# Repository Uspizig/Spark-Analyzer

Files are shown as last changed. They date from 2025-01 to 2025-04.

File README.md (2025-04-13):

# Spark Analyzer: The Programmable USB-C Power Delivery Analyzer & Power Supply

<p align="center">
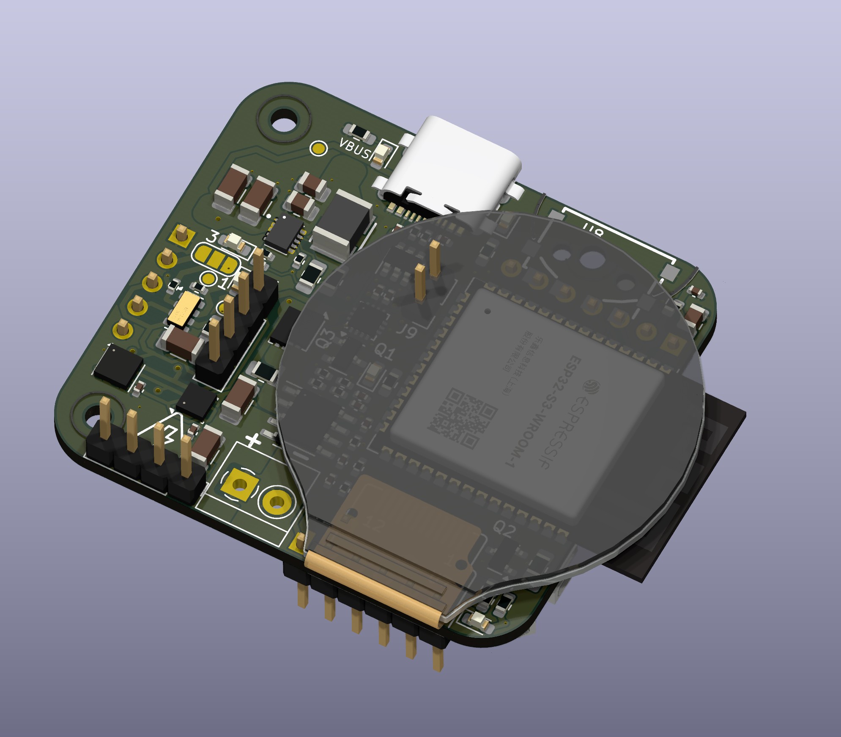
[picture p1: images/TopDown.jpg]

</p>

This is a modification of Spark Analyser to my personal needs. Please check the original Product here [now](https://www.crowdsupply.com/elektrothing/spark-analyzer).

The **Spark Analyzer** excels in power management. It is a versatile ESP32-powered device tailored for enhancing project development and debugging processes. It is fully compatible with USB-C Power Delivery (PD) and also supports the Programmable Power Supply (PPS) feature, allowing for precise control and management of power. Its compact design facilitates easy inline integration with existing setups, providing essential insights and control over power delivery.

Equipped with WiFi and BLE, the Spark Analyzer offers wireless connectivity, enabling developers to remotely monitor and adjust voltage levels, log data, and analyze power consumption through a user-friendly interface. This design prioritizes convenience and efficiency, removing the need for physical buttons and supporting distance operation.

## Features:

1. **Configure USB Power Delivery PD**: When the Spark Analyzer is connected to a USB port that supports Power Delivery (PD), you can configure the output voltage as 5V, 9V, 15V or 20V.

2. **Configure USB Programmable Power Supply PPS**: When the Spark Analyzer is connected to a USB port that supports Programmable Power Supply (PPS), then you can configure the output voltage between 3.3V and 21V in steps of 20 mV. You can also limit the current up to 3A in steps of 50mA.

3. **Power Analysis**: The Spark Analyzer comes with a current sensor. This allows for accurate current draw measurements, essential for understanding power usage in your projects.

4. **Wireless Control**: Untehther your development process with the Spark Analyzer’s wireless capabilities. With both WiFi and BLE, this tool allows remote control and data logging. Users can adjust settings and monitor data from a distance, offering a more flexible development experience.

5. **Open Source & Programmable**: As an open-source device, the Spark Analyzer offers unmatched versatility. It is fully programmable, allowing you to tailor its functionality to your specific applications. This customization extends to software and hardware, opening up endless possibilities for creative and efficient project development.

6. **Compact Design**: Designed for convenience, the Spark Analyzer's compact and sleek form factor allows for seamless integration into existing setups. Its compatibility with USB PD power sources and inline integration capability minimizes the need for additional equipment or extensive redesign, making it a versatile and user-friendly addition to any development environment.

5. **Safety**: Safety is crucial when working with electricity and is at the heart of Spark Analyzer. An integrated output FET allows for software programmable current limit that switches off the power in high-current scenarios.

6. **Data Storage**: Store your Voltage Curves on SD Card and play back voltage ramps

7. **Display**: Monitor live the current status of the Voltage Source

8. **RTC**: Operate the Device in remote areas without Wifi in Standalone mode and still have a proper Time Monitoring

9. **Air Quality**: Measure the Air Qulity with the BME680, BME688 or BME690: Temperature, Humidity, Pressure and eCO² to take actions based on Enviromental Data

10. **Gyro, ACC**: Identify Movement of the Device and take actions.

## Specifications

#### Power
- **Negotiable Power Delivery**: Options of 5 VDC, 9 VDC, 12 VDC, 15 VDC, 20 VDC; max 5 A (100 W at 20 VDC). It is also PPS compatible up to 21 VDC. Note: the Spark Analyzer comes preinstalled with firmware that supports PD. If you want to use PPS you can load this version instead: [WebApp_PPS](https://github.com/tooyipjee/Spark-Analyzer/tree/master/PlatformIO/WebApp_PPS).
- **USB Type-C Port**: For power delivery and integrated JTAG programming.
- **ON Semiconductor [FUSB302MPX](https://www.onsemi.com/pdf/datasheet/fusb302b-d.pdf)**: Programmable USB Type-C control and USB PD communication.
- **ESD Protection**: On D+/D-/CC1/CC2 pins.
- **Texas Instruments [TPS62175DQCT](https://www.ti.com/product/TPS62175/part-details/TPS62175DQCT)**: 3.3 VDC 0.5 A max output DC-DC Step-Down Converter.
- **Power Output**: 3.5 mm, 2-position terminal block.

#### I/O Configuration
- **GPIOs**: 4 GPIOs (I2C, UART, SPI compatible).
- **Power Pins**: 1x 5 VDC and 1x GND.

#### Microcontroller
- **Model**: [ESP32-S3 Wroom](https://www.espressif.com/sites/default/files/documentation/esp32-s3-wroom-1_wroom-1u_datasheet_en.pdf) 
- **Wi-Fi**: 802.11b/g/n.
- **Bluetooth**: BLE 4.2.
- **Flash Memory**: 4 MB.

#### Interface
- **3x LED Indicators**
  - Power On
  - Output Enable
  - Programmable LED/Debug
  - 2 x WS2812-4020 RGB Edge LED
- **Display**
  - GCA9a01 240x240 round Display
  - Backlight can be operated seperatly
- **Buttons**
  - Reset
  - Programmable 2Buttons/Debug
  - Jog Dial
- **Sensors**
  - LSM6 Gyro
  - RV3028 RTC Ultra Low Power
  - 4 GPIOs(3V3 logic) for operating outputs or read out Tacho Signals of FANs
  - BME280 (optional)
  - BME680 (optional) or - BME688 (optional) or - BME690 (optional)
- **Audio Amplifier**
  - MAX983657 AMP for Loudspeaker

#### Programming
- **RX/TX Pins**: For programming.
- **Micro SD Card**: For recall configuration files.
- **USB-C**: Built-in USB JTAG programmer (ESP32-S3), compatible with Arduino. Select ESP32-S3 Dev Board.

#### Output
- **Current Output**: [CC6904SO-10A](https://datasheet.lcsc.com/lcsc/2304140030_Cross-chip-CC6904SO-10A_C469389.pdf).
- **Current Sensor**: Hall Effect Current Sensor.
- **Output Enable**: [DMP3017SFG-7 FET](https://www.diodes.com/assets/Datasheets/products_inactive_data/DMP3017SFG.pdf).

<p align="center">
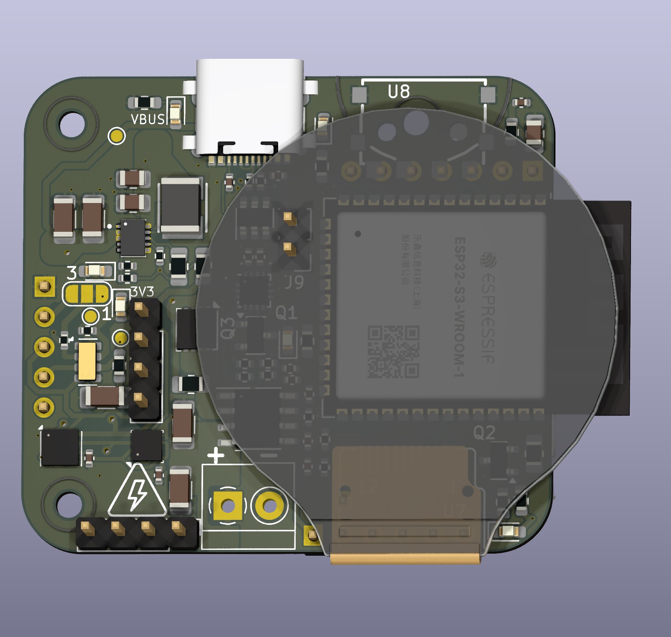
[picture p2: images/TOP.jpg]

</p>

<p align="center">
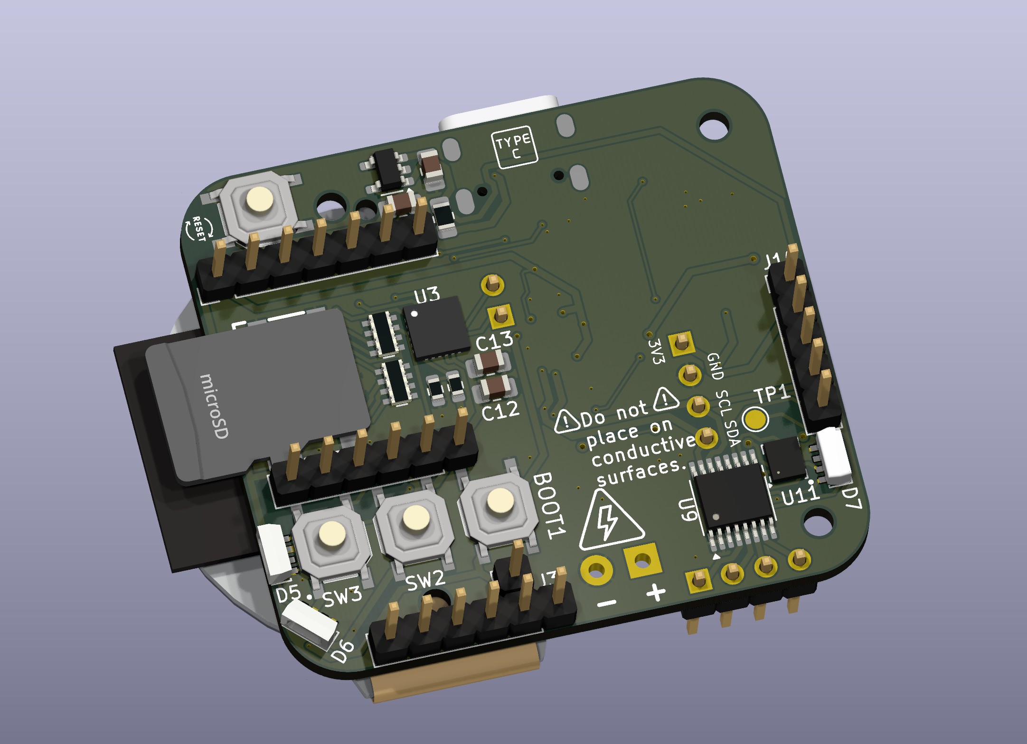
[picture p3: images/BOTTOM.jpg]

</p>

## Spark Analyzer Mobile App

<p align="center">

</p>

> **Note**: The Spark Analyzer Mobile App is currently in active development. The features described below are subject to change as we continue to improve the app.

The Spark Analyzer Mobile App, currently done for [Android](https://play.google.com/store/apps/details?id=com.elektrothing.SparkAnalyzer&hl=en&gl=US) (iOS support is available via [RemoteXY](https://apps.apple.com/us/app/remotexy/id1168130280), is the perfect companion to your Spark Analyzer device. It simplifies monitoring and controlling power delivery with these key features:

- **Voltage Selector**: Easily choose from different voltage levels (5 VDC, 9 VDC, 15 VDC, or 20 VDC) using a user-friendly selector.
- **Output Toggle**: Turn the power output on or off conveniently with a toggle switch.
- **Current Logging**: Save current draw as a .csv file.
- **Current Limit**: Ability to set a software current trip as a safety feature.
- **Read-time Display**: View current set point, current draw and output enable in real time on your phone.

### Key Features:

- **Voltage Selector**: The app comes with a user-friendly voltage selector that allows you to easily choose from the different voltage levels supported by the UCPD protocol. Whether you need 5V, 9V, 15V, or 20V, switching between these options is just a tap away.

- **Output Toggle**: Need to turn the power output on or off? The app features a convenient toggle switch that gives you full control over the Spark Analyzer's output, making it simple to manage your device remotely.

- **Current Draw Chart**: Keep an eye on your project's power consumption with the app's real-time current draw chart. This feature provides a graphical representation of the current being drawn, helping you to monitor and optimize your power usage effectively.

### Future Developments:

The Spark Analyzer Mobile App is continuously being improved, with several new features in the pipeline. Upcoming updates will include the ability to export logs for further analysis, set current limits to prevent overcurrent scenarios, and much more.

## Testing for Performance

At the heart of Spark Analyzer's design is a commitment to reliability and performance. To ensure that Spark Analyzer stands up to real-world demands, we subjected it to testing under use conditions.

### Max Current Test: 3A at 9V
Under a load condition of 3A at 9V, Spark Analyzer showcased its robust power delivery capabilities without any hitches.

<p align="center">

</p>

### Max Voltage Test: 1.5A at 20V
Even at its maximum voltage output of 20V with a 1.5A load, Spark Analyzer continued to perform seamlessly, demonstrating its versatility and reliability.

<p align="center">

</p>

## License

MIT License

Copyright (c) 2023 elektroThing

Permission is hereby granted, free of charge, to any person obtaining a copy
of this software and associated documentation files (the "Software"), to deal
in the Software without restriction, including without limitation the rights
to use, copy, modify, merge, publish, distribute, sublicense, and/or sell
copies of the Software, and to permit persons to whom the Software is
furnished to do so, subject to the following conditions:

The above copyright notice and this permission notice shall be included in all
copies or substantial portions of the Software.

THE SOFTWARE IS PROVIDED "AS IS", WITHOUT WARRANTY OF ANY KIND, EXPRESS OR
IMPLIED, INCLUDING BUT NOT LIMITED TO THE WARRANTIES OF MERCHANTABILITY,
FITNESS FOR A PARTICULAR PURPOSE AND NONINFRINGEMENT. IN NO EVENT SHALL THE
AUTHORS OR COPYRIGHT HOLDERS BE LIABLE FOR ANY CLAIM, DAMAGES OR OTHER
LIABILITY, WHETHER IN AN ACTION OF CONTRACT, TORT OR OTHERWISE, ARISING FROM,
OUT OF OR IN CONNECTION WITH THE SOFTWARE OR THE USE OR OTHER DEALINGS IN THE
SOFTWARE.

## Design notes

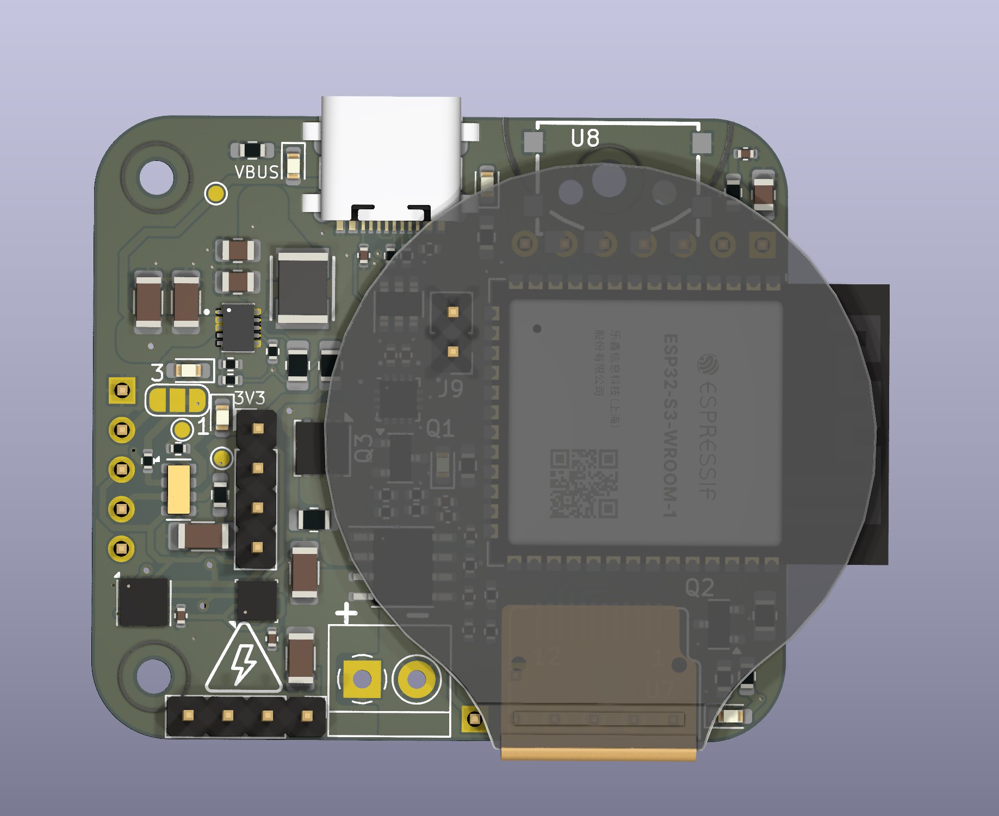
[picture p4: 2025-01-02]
images/SparkAnalyzer.jpg

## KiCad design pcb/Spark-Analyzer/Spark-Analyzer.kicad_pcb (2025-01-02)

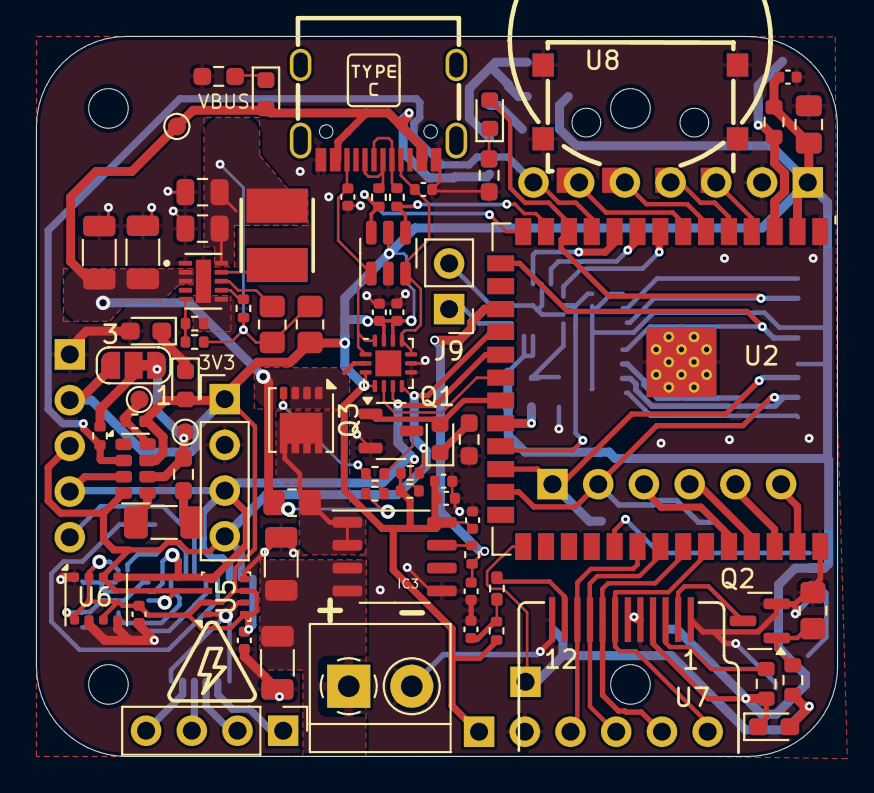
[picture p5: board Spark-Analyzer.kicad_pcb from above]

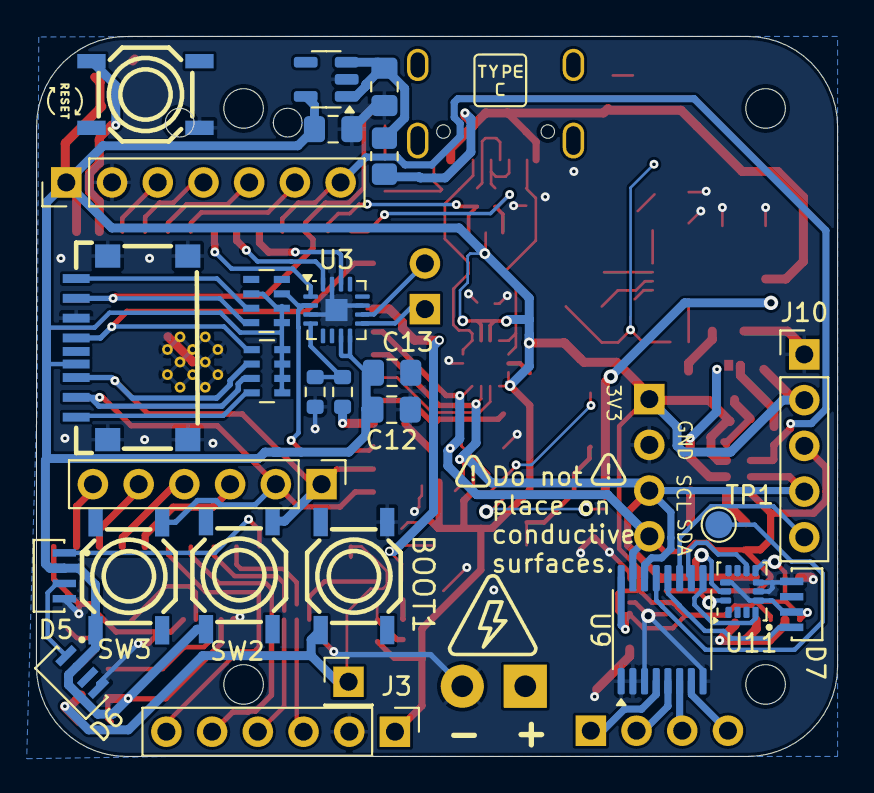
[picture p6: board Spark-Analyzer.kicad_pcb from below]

Board: 4 copper layers, 44.5 x 40.0 mm, 107 parts (28 on the bottom side), 78 nets.

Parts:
 : LOGO; highVoltage
 #2: LOGO; highVoltage
BOOT1: SW_Push; SW-SMD_4P-CORR-L5.2-W5.2-P3.70-LS6.4
C1, C20, C21, C22: 10u_1206; C_1206_3216Metric
C2: 22u; C_0805_2012Metric
C3: 10u; C_0805_2012Metric
C4, C5: 100p; C_0402_1005Metric
C6, C7, C8, C9, C11, C14, C15, C16, C24, C25: 100nF; C_0402_1005Metric
C10, C12, C13: 1uF; C_0805_2012Metric_Pad1.18x1.45mm_HandSolder
C17, C18: 4.7uF50V; C_0805_2012Metric_Pad1.18x1.45mm_HandSolder
C19: 220uF; C_1206_3216Metric_Pad1.33x1.80mm_HandSolder
D1, D2, D4: Green_0603; LED_0603_1608Metric
D3: Yellow_0603; LED_0603_1608Metric
D5, D6, D7: WS2812B-4020; LED_WS2812B-4020
H1, H2, H3, H4: MountingHole; MountingHole_2.2mm_M2
IC2: FUSB302MPX; WQFN-14-1EP_2.5x2.5mm_P0.5mm_EP1.45x1.45mm
IC3: CC6904SO-10A; SOP-8_3.9x4.9mm_P1.27mm
IC4: TPS62175DQCT; SON50P300X200X80-11N
J1: GT-USB-7010; USB-C_SMD-TYPE-C-31-M-12
J3, J12: Conn_01x06_Pin; PinHeader_1x06_P2.54mm_Vertical
J4, J7: Conn_01x04; PinHeader_1x04_P2.54mm_Vertical
J5: Conn_01x01; PinHeader_1x01_P2.54mm_Vertical
J6: Micro_SD_Card_Det_US; TF-SMD_XKTF-0803-0
J8: Conn_01x07_Pin; PinHeader_1x07_P2.54mm_Vertical
J9: Conn_01x02_Pin; PinHeader_1x02_P2.54mm_Vertical
J10: Conn_01x05; PinHeader_1x05_P2.54mm_Vertical
J11: KF350-3.5-2P; TerminalBlock_4Ucon_1x02_P3.50mm_Horizontal
JP1: SolderJumper_3_Bridged12; SolderJumper-3_P1.3mm_Bridged12_RoundedPad1.0x1.5mm_NumberL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
L1: 10uH; INDPM4040X300N
Q1: DTC143ECA-TP; SOT-23-3
Q2: 2N7002; SOT-23
Q3: DMP3017SFG-7; Diodes_PowerDI3333-8
R1: 100k; R_0402_1005Metric
R2: 1M2; R_0402_1005Metric
R3: 383k; R_0402_1005Metric
R4, R5: 0; R_0805_2012Metric_Pad1.20x1.40mm_HandSolder
R6, R7: 22; R_0402_1005Metric
R8: 100; R_0402_1005Metric
R9, R16: 2.7k; LED_0603_1608Metric_Pad1.05x0.95mm_HandSolder
R10, R12: 10k; R_0603_1608Metric
R11: 1M; R_0805_2012Metric_Pad1.20x1.40mm_HandSolder
R13, R14, R19, R24: 10k; R_0402_1005Metric
R15: 0R; R_0402_1005Metric_Pad0.72x0.64mm_HandSolder
R17, R18, R22: 2.7k; R_0603_1608Metric_Pad0.98x0.95mm_HandSolder
R20: 1k; R_0402_1005Metric
R21: DNF_0805; R_0805_2012Metric_Pad1.20x1.40mm_HandSolder
R23: 22; R_0603_1608Metric
R25: N.C.; R_0603_1608Metric
R26: 300K; R_0603_1608Metric
R27, R29: 10K; R_0402_1005Metric
R28: 0R; R_0805_2012Metric_Pad1.20x1.40mm_HandSolder
R30: 300R; R_0603_1608Metric_Pad0.98x0.95mm_HandSolder
RES1: SW_Push; SW-SMD_4P-CORR-L5.2-W5.2-P3.70-LS6.4
RN2, RN3: R_Pack04_Split; R_Array_Concave_4x0603
SW2, SW3: SW_Push; SW-SMD_4P-CORR-L5.2-W5.2-P3.70-LS6.4
TP1: TestPoint; TestPoint_Pad_D1.5mm
TP2, TP3, TP4: TestPoint; TestPoint_Pad_D1.0mm
U1: SRV05-4; SOT-23-6
U2: ESP32-S3-WROOM-1
U3: MAX98357A; TQFN-16-1EP_3x3mm_P0.5mm_EP1.23x1.23mm
U4: RV3032; MicroCrystal_C7_SON-8_1.5x3.2mm_P0.9mm
U5: BME280; Bosch_LGA-8_2.5x2.5mm_P0.65mm_ClockwisePinNumbering
U6: BME680; Bosch_LGA-8_3x3mm_P0.8mm_ClockwisePinNumbering
U7: GC9A01_IPS_display; GC9A01_IPS_display_reversed
U8: SIQ-02FVS3; SW-SMD_SIQ-02FVS3_1
U9: TCA9554PW; TSSOP-16_4.4x5mm_P0.65mm
U10: RT9013; SOT-23-5
U11: LSM6DSL; LGA-14_3x2.5mm_P0.5mm_LayoutBorder3x4y

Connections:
+3V3: C6.2, C7.1, C9.1, C10.1, C12.2, C13.1, C14.2, C15.1, C16.1, C18.2, C24.2, C25.2, D1.2 (A), D5.2 (VDD), D6.2 (VDD), D7.2 (VDD), IC2.3 (VDD_1), IC2.4 (VDD_2), IC2.12 (VCONN_1), IC2.13 (VCONN_2), IC3.8 (VCC), J3.1, J6.4 (VDD), J7.1, J8.1, J10.2, JP1.3 (B), R4.2, R9.1, R12.1, R13.1, R14.1, R23.1, R24.1, R29.2, RN2.1 (R1.1), RN2.2 (R2.1), RN2.6 (R3.2), RN3.5 (R4.2), RN3.6 (R3.2), RN3.7 (R2.2), RN3.8 (R1.2), SW2.2, SW3.2, U1.5 (VP), U2.2 (3V3), U3.7 (VDD), U3.8 (VDD), U4.7 (VDD), U5.2 (CSB), U5.6 (VDDIO), U5.8 (VDD), U6.2 (CSB), U6.6 (VDDIO), U6.8 (VDD), U7.4 (VDD), U9.16 (VDD), U10.5 (VOUT), U11.5 (VDDIO), U11.8 (VDD), U11.12 (CS)
/Current Sensor + Output Control/BSST: IC3.1 (IP+), IC3.2 (IP+), Q3.5 (D_1), R21.2
/Current Sensor + Output Control/OUTPUT_EN: D3.2 (A), Q1.1, U2.21 (GPIO13/TOUCH13/ADC2_CH2/FSPIQ/FSPIIO7/S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)
/Current Sensor + Output Control/VOUT: C1.1, C22.1, IC3.3 (IP-), IC3.4 (IP-), J11.1
/Current Sensor + Output Control/V_CURRENT: C8.1, R8.2, U2.17 (GPIO9/TOUCH9/ADC1_CH8/FSPIHD/SUBSPIHD)
/Microcontroller/AUDIO_CLK: U2.9 (GPIO16/U0CTS/ADC2_CH5/XTAL_32K_NH5), U3.16 (BCLK)
/Microcontroller/AUDIO_DAT: U2.8 (GPIO15/U0RTS/ADC2_CH4/XTAL_32K_P), U3.1 (DIN)
/Microcontroller/AUDIO_GAIN: RN2.3 (R3.1), U2.23 (GPIO21), U3.2 (GAIN_SLOT)
/Microcontroller/AUDIO_LR: U2.10 (GPIO17/U1TXD/ADC2_CH6), U3.14 (LRCLK)
/Microcontroller/AUDIO_SD: R26.2, U2.22 (GPIO14/TOUCH14/ADC2_CH3/FSPIWP/FSPIDQS/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)
/Microcontroller/BLK: BOOT1.2, J5.1, R9.2, R10.2, U2.27 (GPIO0/BOOT)
/Microcontroller/CMD: J6.3 (CMD), J12.1, RN3.2 (R2.1), SW2.1, U2.24 (GPIO47/SPICLK_P/SUBSPICLK_P_DIFF)
/Microcontroller/DAT0: D4.2 (A), J6.7 (DAT0), RN2.8 (R1.2), U2.12 (GPIO8/TOUCH8/ADC1_CH7/SUBSPICS1)
/Microcontroller/DAT1: J6.8 (DAT1), RN2.7 (R2.2)
/Microcontroller/DAT3: J6.2 (DAT3/CD), J12.2, RN3.3 (R3.1), SW3.1, U2.25 (GPIO48/SPICLK_N/SUBSPICLK_N_DIFF)
/Microcontroller/EN: R12.2, RES1.1, U2.3 (EN)
/Microcontroller/GPIO1: J12.6, U2.39 (GPIO1/TOUCH1/ADC1_CH0)
/Microcontroller/GPIO2: J12.5, U2.38 (GPIO2/TOUCH2/ADC1_CH1)
/Microcontroller/GPIO4: J8.3, U2.4 (GPIO4/TOUCH4/ADC1_CH3), U8.B
/Microcontroller/GPIO5: J8.4, U2.5 (GPIO5/TOUCH5/ADC1_CH4), U8.C
/Microcontroller/GPIO6: J8.5, U2.6 (GPIO6/TOUCH6/ADC1_CH5), U8.S
/Microcontroller/GPIO7: J8.6, U2.7 (GPIO7/TOUCH7/ADC1_CH6), U8.A
/Microcontroller/GPIO38: D5.1 (DIN), U2.31 (GPIO38/FSPIWP/SUBSPIWP)
/Microcontroller/INT1: U9.9 (P4), U11.4 (INT1)
/Microcontroller/INT2: U9.10 (P5), U11.9 (INT2)
/Microcontroller/INT_N: IC2.5 (INT_N), U2.20 (GPIO12/TOUCH11/ADC2_CH0/FSPICS0/FSPIIO4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)
/Microcontroller/LEDK: Q2.3 (D), U7.2 (LEDK)
/Microcontroller/LED_DIS: R23.2, U7.3 (LEDA)
/Microcontroller/MOSI: J3.3, U2.32 (MTCK/GPIO39/CLK_OUT3/SUBSPICS1), U7.10 (SDI)
/Microcontroller/RES_DIS: R15.1, U7.11 (~RESET)
/Microcontroller/RV3028_Int: J8.7, R27.2, U2.11 (GPIO18/U1RXD/ADC2_CH7/CLK_OUT3), U4.2 (INT)
/Microcontroller/SCK: J3.4, U2.33 (MTDO/GPIO40/CLK_OUT2), U7.9 (SCK)
/Microcontroller/SCL: IC2.6 (SCL), J7.3, J10.4, R14.2, U2.19 (GPIO11/TOUCH11/ADC2_CH0/FSPICS0/FSPIIO4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), U4.3 (SCL), U5.4 (SCK), U6.4 (SCK), U9.14 (SCL), U11.13 (SCL)
/Microcontroller/SDA: IC2.7 (SDA), J7.4, J10.3, R13.2, U2.18 (GPIO10/TOUCH10/ADC1_CH9/FSPICS0/FSPIIO4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), U4.4 (SDA), U5.3 (SDI), U6.3 (SDI), U9.15 (SDA), U11.14 (SDA)
/Microcontroller/SDCK: J6.5 (CLK), RN3.1 (R1.1), U2.15 (GPIO3/TOUCH3/ADC1_CH2)
/Microcontroller/SQW: J10.5, U9.11 (P6)
/Microcontroller/TFT_CS: J3.5, U2.34 (MTDI/GPIO41/CLK_OUT1), U7.8 (~CS)
/Microcontroller/TFT_DC: J3.6, U2.35 (MTMS/GPIO42), U7.7 (D/C)
/Microcontroller/U0RXD: J12.3, U2.36 (U0RXD/GPIO44/CLK_OUT2)
/Microcontroller/U0TXD: J12.4, U2.37 (U0TXD/GPIO43/CLK_OUT1)
/Microcontroller/USB_DN: R6.2, U1.4 (IO3), U2.13 (GPIO19/U1RTS/ADC2_CH8/CLK_OUT2/USB_D-)
/Microcontroller/USB_DP: R7.1, U1.6 (IO4), U2.14 (GPIO20/U1CTS/ADC2_CH9/CLK_OUT1/USB_D+)
GND: BOOT1.1, C1.2, C2.2, C3.2, C4.2, C5.2, C6.1, C7.2, C8.2, C9.2, C10.2, C11.2, C12.1, C13.2, C14.1, C15.2, C16.2, C17.1, C18.1, C19.2, C20.2, C21.2, C22.2, C24.1, C25.1, D5.4 (VSS), D6.4 (VSS), D7.4 (VSS), IC2.8 (GND_1), IC2.9 (GND_2), IC3.5 (GND), IC4.1 (PGND), IC4.6 (AGND), IC4.11 (EP), J1.A1 (GND), J1.A12 (GND), J1.B1 (GND), J1.B12 (GND), J3.2, J6.6 (VSS), J6.10 (SHELL), J6.11 (SHELL), J6.12 (SHELL), J6.13 (SHELL), J7.2, J8.2, J10.1, J11.2, Q1.2, Q2.2 (S), R3.2, R11.1, R16.2, R17.2, R18.2, R22.2, R25.1, RES1.2, U1.2 (VN), U2.1 (GND), U2.40 (GND), U2.41 (GND), U3.3 (GND), U3.11 (GND), U3.15 (GND), U3.17 (PAD), U4.5 (GND), U5.1 (GND), U5.5 (SDO), U5.7 (GND), U6.1 (GND), U6.5 (SDO), U6.7 (GND), U7.1 (GND), U7.5 (GND), U7.6 (GND), U7.12 (GND), U8.1 (EH), U8.2 (EH), U8.5 (EH), U8.6 (EH), U9.1 (A0), U9.2 (A1), U9.3 (A2), U9.8 (GND), U10.2 (GND), U11.6 (GND), U11.7 (GND)
unnamed: C11.1, R15.2, R24.2
unnamed: C19.1, R30.1
unnamed: D1.1 (K), R16.1
unnamed: D2.1 (K), R17.1
unnamed: D3.1 (K), R18.1
unnamed: D4.1 (K), R22.1
unnamed: D5.3 (DOUT), D6.1 (DIN)
unnamed: D7.1 (DIN), U9.12 (P7)
unnamed: C5.1, IC2.10 (CC1_1), IC2.11 (CC1_2), J1.A5 (CC1), U1.3 (IO2)
unnamed: C4.1, IC2.1 (CC2_1), IC2.14 (CC2_2), J1.B5 (CC2), U1.1 (IO1)
unnamed: IC3.7 (OUT), R8.1
unnamed: IC4.5 (FB), R2.2, R3.1
unnamed: IC4.7 (PG), R1.2
unnamed: IC4.8 (SLEEP), R5.1
unnamed: IC4.9 (SW), L1.1
unnamed: C2.1, C3.1, IC4.10 (VOS), L1.2, R1.1, R2.1, R4.1, R5.2
unnamed: J1.A6 (D+), J1.B6 (D+), R7.2
unnamed: J1.A7 (D-), J1.B7 (D-), R6.1
unnamed: J4.1, U9.4 (P0)
unnamed: J4.2, U9.5 (P1)
unnamed: J4.3, U9.6 (P2)
unnamed: J4.4, U9.7 (P3)
unnamed: J6.1 (DAT2), RN3.4 (R4.1)
unnamed: J9.1, U3.9 (OUTP)
unnamed: J9.2, U3.10 (OUTN)
unnamed: JP1.2 (C), R27.1
unnamed: Q1.3, R20.2
unnamed: Q2.1 (G), R10.1, R11.2
unnamed: Q3.4 (G), R19.2, R20.1
unnamed: R25.2, R26.1, U3.4 (~SD_MODE)
unnamed: R29.1, TP2.1, U4.8 (EVI)
unnamed: TP1.1, U9.13 (~INT)
unnamed: C17.2, R28.1, U10.1 (VIN), U10.3 (EN)
VBUS: C20.1, C21.1, D2.2 (A), IC2.2 (VBUS), IC4.2 (VIN), IC4.3 (EN), J1.A4 (VBUS), J1.A9 (VBUS), J1.B4 (VBUS), J1.B9 (VBUS), Q3.1, Q3.2, Q3.3, R19.1, R21.1, R28.2, TP4.1
VPP: JP1.1 (A), R30.2, TP3.1, U4.6 (V_BCU)

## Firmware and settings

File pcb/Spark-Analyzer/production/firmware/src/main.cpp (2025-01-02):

/*
   NOTICE:
   This firmware for the Web App is developed using PlatformIO, an open-source ecosystem
   for IoT development. It leverages the SPIFFS (SPI Flash File System) for handling
   on-device file storage. Ensure that PlatformIO and necessary libraries are installed
   before compiling and uploading this firmware to your device.

   -- Web App Firmware --

   This script is the firmware for the Web App, designed to provide a user interface
   for monitoring and controlling power delivery in smart home applications. Key features
   include real-time current monitoring, voltage adjustment, and power output control.

   Key components and libraries:
     - ESPAsyncWebServer: For handling HTTP requests and serving the web interface.
     - EEPROM: To store and retrieve persistent settings such as the voltage level.
     - WiFiManager: To facilitate easy WiFi connectivity and configuration.
     - SPIFFS: For storing and accessing web interface files.

   Instructions for Loading the Firmware and Web Interface:
   1. Open the project in PlatformIO.
   2. Place the HTML file inside the 'data' directory of your PlatformIO project.
   3. Compile the firmware using PlatformIO. Ensure all library dependencies are resolved.
   4. Upload the firmware to your device using PlatformIO's upload functionality.
   5. Use PlatformIO's "Upload Filesystem Image" command to upload the contents of the 'data' directory
      to your device. This step ensures that the HTML file is stored in the SPIFFS.
   6. When done - connect your Spark Analyzer to your local WiFi using your phone/computer and searching for "Spark Analyzer" access point.
   7. Navigate to 192.168.4.1, and follow the web app to setup the device on your WiFi.
   8. Open serial terminal and the Spark Analyzer will print out it's IP address, navigate to that IP address and you should see the web app.

   Developed by Jason Too
   License: MIT

   MIT License
   Copyright (c) 2023 elektroThing

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
   THE SOFTWARE IS PROVIDED "AS IS", WITHOUT WARRANTY OF ANY KIND, EXPRESS OR IMPLIED,
   INCLUDING BUT NOT LIMITED TO THE WARRANTIES OF MERCHANTABILITY, FITNESS FOR A
   PARTICULAR PURPOSE AND NONINFRINGEMENT. IN NO EVENT SHALL THE AUTHORS OR COPYRIGHT
   HOLDERS BE LIABLE FOR ANY CLAIM, DAMAGES OR OTHER LIABILITY, WHETHER IN AN ACTION
   OF CONTRACT, TORT OR OTHERWISE, ARISING FROM, OUT OF OR IN CONNECTION WITH THE
   SOFTWARE OR THE USE OR OTHER DEALINGS IN THE SOFTWARE.
*/

#include <Arduino.h>
#include <Wire.h>
#include <PD_UFP.h>
#include <WiFi.h>
#include <WiFiManager.h> // Include the WiFiManager library
#include <ESPAsyncWebServer.h>
#include <Preferences.h>
#include "index_html.h"
#include <NimBLEDevice.h>

void initializeSerialAndPins();
void initializeUSB_PD();
void updateStatus();
void processCurrentReading();
int readFilteredADC(int pin);

// User-configurable constants
#define FILTER_LENGTH 10
#define INITIAL_OUTPUT_STATE 0 // 1 for On, 0 for Off
#define VOLTAGE 5

// Filter variables
int adcSamples[FILTER_LENGTH];
int adcIndex = 0;
int adcSum = 0;

unsigned long lastUpdateTime = 0;
const unsigned long updateInterval = 100; // Set sample rate
const int usb_pd_int_pin = 10;
const int output_pin = 3;
const int current_pin = 2;
const int debug_led = 8;
int current = 0;
bool output = INITIAL_OUTPUT_STATE;
int voltage = VOLTAGE;
int adcError = 0;

PD_UFP_c PD_UFP;
Preferences preferences;

void handleVoltageChange(AsyncWebServerRequest *request)
{
  if (request->hasParam("voltage"))
  {
    int newVoltage = request->getParam("voltage")->value().toInt();
    if (newVoltage != voltage)
    {
      // Write new voltage to Preferences
      preferences.putUInt("voltage", newVoltage);
      esp_restart(); // Restart ESP32 to apply new voltage setting
    }
    else
    {
      request->send(200, "text/plain", "Voltage unchanged");
    }
    request->send(200, "text/plain", String(voltage));
  }
  else
  {
    request->send(400, "text/plain", "Voltage parameter missing");
  }
}

void handleOutputControl(AsyncWebServerRequest *request)
{
  if (request->hasParam("output"))
  {
    String outputState = request->getParam("output")->value();
    if (outputState == "1")
    {
      output = true;
      digitalWrite(output_pin, HIGH); // Turn output ON
      request->send(200, "text/plain", "Output Enabled");
    }
    else if (outputState == "0")
    {
      output = false;
      digitalWrite(output_pin, LOW); // Turn output OFF
      request->send(200, "text/plain", "Output Disabled");
    }
    else
    {
      request->send(400, "text/plain", "Invalid output state");
    }
  }
  else
  {
    request->send(400, "text/plain", "Output parameter missing");
  }
}
// Create AsyncWebServer object on port 80
AsyncWebServer server(80);
void setup()
{
  // Initialize Preferences with namespace "storage". False for read/write mode.
  preferences.begin("storage", false);
  // Retrieve stored voltage value or default to VOLTAGE if not set.
  voltage = preferences.getUInt("voltage", VOLTAGE);
  
  pinMode(debug_led, OUTPUT); // Set debug LED as an output before blinking
  // Blink debug LED 5 times
  for (int i = 0; i < 5; i++)
  {
    digitalWrite(debug_led, HIGH);
    delay(250); // Adjust delay time as needed
    digitalWrite(debug_led, LOW);
    if (i < 4) // Avoid delay after the last blink
    {
        delay(500);
    }
  }
  WiFiManager wifiManager;                   // Initialize WiFiManager
  wifiManager.autoConnect("Spark Analyzer"); // Auto-connect to WiFi. Change "ESP32_Device" to your desired AP name

  Serial.begin(115200);
  Serial.println("Connected to WiFi");

  initializeUSB_PD();
  for (int i = 0; i < 30; i++)
  {
    processCurrentReading();
  }
  initializeSerialAndPins();

  Serial.print("To access the web app, open your browser and navigate to -> ");
  Serial.println(WiFi.localIP());

  server.on("/", HTTP_GET, [](AsyncWebServerRequest *request)
            { request->send(200, "text/html", index_html); });
  server.on("/current", HTTP_GET, [](AsyncWebServerRequest *request)
            { request->send(200, "text/plain", String(current)); });
  server.on("/get_voltage", HTTP_GET, [](AsyncWebServerRequest *request)
            { request->send(200, "text/plain", String(voltage)); });
  server.on("/set_voltage", HTTP_GET, handleVoltageChange);

  server.on("/set_output", HTTP_GET, handleOutputControl);
  server.begin();

  // Debug pin lights up when ready.
  pinMode(debug_led, OUTPUT);
  digitalWrite(debug_led, HIGH);

  String ipAddress = WiFi.localIP().toString();

  // Prepare the device name with the IP address embedded
  String deviceName = "SparkAnalyzer " + ipAddress;

  // Initialize BLE with the new device name
  BLEDevice::init(deviceName.c_str());

  // Get a reference to the existing advertising
  NimBLEAdvertising *pAdvertising = BLEDevice::getAdvertising();

  // Since we're now using the device name to convey the IP address,
  // we don't need to set custom advertising data for the IP.
  // Just configure the advertisement to include the service UUID you want to advertise.
  // Note: BLEUUID needs to be adjusted as per your application's requirement.
  pAdvertising->addServiceUUID(BLEUUID("1234"));

  // Start advertising
  BLEDevice::startAdvertising();
}

void loop()
{
  updateStatus();
  processCurrentReading();
}

// Initialize Serial and Pin Modes
void initializeSerialAndPins()
{
  Serial.begin(115200);
  Serial.println("Initializing...");

  pinMode(usb_pd_int_pin, INPUT);
  pinMode(output_pin, OUTPUT);
  digitalWrite(output_pin, LOW);

  pinMode(current_pin, INPUT);
}

// Initialize USB Power Delivery
void initializeUSB_PD()
{
  Wire.begin(1, 0);
  Wire.setClock(400000);
  if (voltage == 5)
  {
    PD_UFP.init(usb_pd_int_pin, PD_POWER_OPTION_MAX_5V);
  }
  else if (voltage == 9)
  {
    PD_UFP.init(usb_pd_int_pin, PD_POWER_OPTION_MAX_9V);
  }
  else if (voltage == 12)
  {
    PD_UFP.init(usb_pd_int_pin, PD_POWER_OPTION_MAX_12V);
  }
  else if (voltage == 15)
  {
    PD_UFP.init(usb_pd_int_pin, PD_POWER_OPTION_MAX_15V);
  }
  else if (voltage == 20)
  {
    PD_UFP.init(usb_pd_int_pin, PD_POWER_OPTION_MAX_20V);
  }
}

// Update status at intervals
void updateStatus()
{
  if (millis() - lastUpdateTime >= updateInterval)
  {
    lastUpdateTime = millis();
    // Add any periodic update logic here
  }
  PD_UFP.run();
}

// Process current reading and adjust LED status
void processCurrentReading()
{
  if (output)
  {
    digitalWrite(output_pin, HIGH);
  }
  else
  {
    adcError = readFilteredADC(current_pin);
    digitalWrite(output_pin, LOW);
  }
  current = 5.6865 * (readFilteredADC(current_pin) - adcError);
}

// Reads ADC value with a moving average filter
int readFilteredADC(int pin)
{
  int newSample = analogRead(pin);
  adcSum -= adcSamples[adcIndex];
  adcSamples[adcIndex] = newSample;
  adcSum += newSample;
  adcIndex = (adcIndex + 1) % FILTER_LENGTH;
  return adcSum / FILTER_LENGTH;
}
